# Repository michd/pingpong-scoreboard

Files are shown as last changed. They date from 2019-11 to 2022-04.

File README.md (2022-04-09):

# Pingpong Scoreboard

This is an electronics hardware and firmware project for a Pingpong scoreboard.

Its user interface consists for a 4-digit 7 segment display, a few LEDs, a button for each side of the table, and a button for the scoreboard.

The scoreboard keeps track of the score within the game, within the set (games won each side since power-up) and of the overall score (games won each side, all time).

## Hardware

Since the program for this is really simple, and there isn't much I/O, an ATTiny84 was chose as the microcontroller, of the Microchip/AVR range. It is programmed via ISP, and I'm programming it using a Waveshare AVRISP MKII.

The display is driven using a Maxim Integrated MAX7219. The few extra indication LEDs are also driven by that, since the chip supports up to 8 digits, and the project only requires 4.

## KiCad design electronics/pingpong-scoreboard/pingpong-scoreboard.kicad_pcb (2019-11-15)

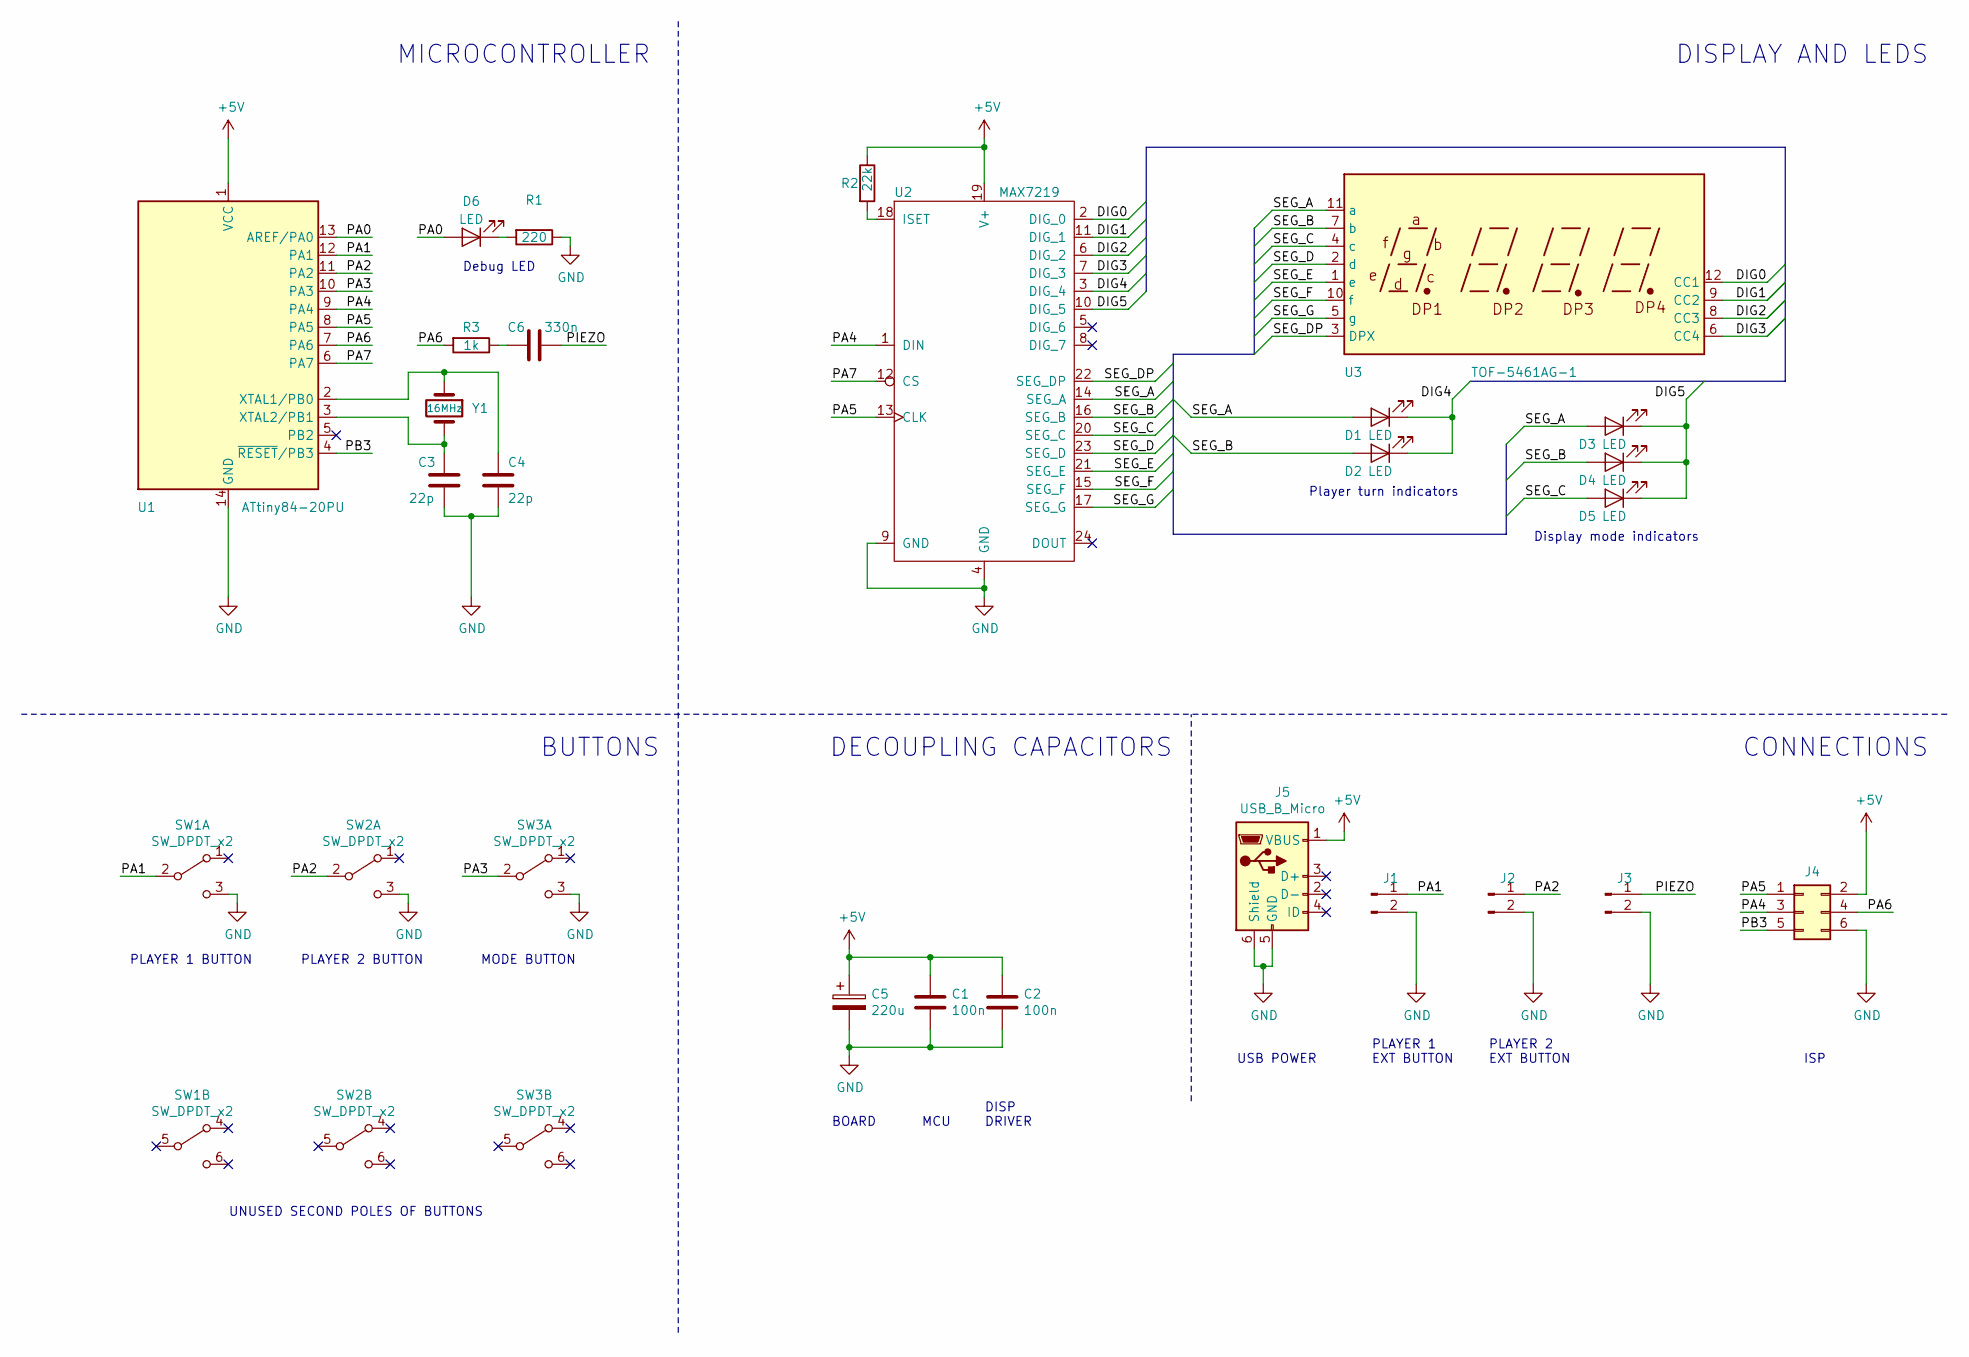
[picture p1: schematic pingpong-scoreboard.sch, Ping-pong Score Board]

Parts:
C1, C2: 100n; C_Disc_D4.3mm_W1.9mm_P5.00mm
C3, C4: 22p; C_Disc_D4.3mm_W1.9mm_P5.00mm
C5: 220u; CP_Radial_D6.3mm_P2.50mm
C6: 330n; C_0603_1608Metric
D1, D2: LED; LED_D5.0mm_Clear
D3, D4, D5: LED; LED_D5.0mm
D6: LED; LED_0603_1608Metric
J1, J2, J3: Conn_01x02_Male; PinHeader_1x02_P2.54mm_Horizontal
J4: Conn_02x03_Odd_Even; IDC-Header_2x03_P2.54mm_Horizontal
J5: USB_B_Micro; USB_Micro-B_Amphenol_10103594-0001LF_Horizontal
R1: 220; R_0603_1608Metric
R2: 22k; R_0603_1608Metric
R3: 1k; R_0603_1608Metric
SW1, SW2, SW3: SW_DPDT_x2; 6-pin-momentary-push-button
U1: ATtiny84-20PU; DIP-14_W7.62mm_LongPads
U2: MAX7219; DIP-24_W7.62mm_LongPads
U3: TOF-5461AG-1; CA56-12CGKWA
Y1: 16MHz; Resonator-2Pin_W10.0mm_H5.0mm

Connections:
+5V: C1.1, C2.1, C5.1, J4.2, J5.1 (VBUS), R2.1, U1.1 (VCC), U2.19 (V+)
/DIG0: U2.2 (DIG_0), U3.12 (CC1)
/DIG1: U2.11 (DIG_1), U3.9 (CC2)
/DIG2: U2.6 (DIG_2), U3.8 (CC3)
/DIG3: U2.7 (DIG_3), U3.6 (CC4)
/DIG4: D1.1 (K), D2.1 (K), U2.3 (DIG_4)
/DIG5: D3.1 (K), D4.1 (K), D5.1 (K), U2.10 (DIG_5)
/PA0: D6.2 (A), U1.13 (AREF/PA0)
/PA1: J1.1, SW1.2 (B), U1.12 (PA1)
/PA2: J2.1, SW2.2 (B), U1.11 (PA2)
/PA3: SW3.2 (B), U1.10 (PA3)
/PA4: J4.3, U1.9 (PA4), U2.1 (DIN)
/PA5: J4.1, U1.8 (PA5), U2.13 (CLK)
/PA6: J4.4, R3.2, U1.7 (PA6)
/PA7: U1.6 (PA7), U2.12 (CS)
/PB3: J4.5, U1.4 (~RESET~/PB3)
/PIEZO: C6.1, J3.1
/SEG_A: D1.2 (A), D3.2 (A), U2.14 (SEG_A), U3.11 (a)
/SEG_B: D2.2 (A), D4.2 (A), U2.16 (SEG_B), U3.7 (b)
/SEG_C: D5.2 (A), U2.20 (SEG_C), U3.4 (c)
/SEG_D: U2.23 (SEG_D), U3.2 (d)
/SEG_DP: U2.22 (SEG_DP), U3.3 (DPX)
/SEG_E: U2.21 (SEG_E), U3.1 (e)
/SEG_F: U2.15 (SEG_F), U3.10 (f)
/SEG_G: U2.17 (SEG_G), U3.5 (g)
GND: C1.2, C2.2, C3.2, C4.2, C5.2, J1.2, J2.2, J3.2, J4.6, J5.5 (GND), J5.6 (Shield), R1.1, SW1.3 (C), SW2.3 (C), SW3.3 (C), U1.14 (GND), U2.4 (GND), U2.9 (GND)
unnamed: C3.1, U1.3 (XTAL2/PB1), Y1.2
unnamed: C4.1, U1.2 (XTAL1/PB0), Y1.1
unnamed: C6.2, R3.1
unnamed: D6.1 (K), R1.2
unnamed: R2.2, U2.18 (ISET)

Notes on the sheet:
Player turn indicators
Display mode indicators
PLAYER 1 BUTTON
PLAYER 2 BUTTON
MODE BUTTON
UNUSED SECOND POLES OF BUTTONS
Debug LED
PLAYER 1 EXT BUTTON
PLAYER 2 EXT BUTTON
ISP
USB POWER
CONNECTIONS
BOARD
MCU
DISP DRIVER
DECOUPLING CAPACITORS
BUTTONS
MICROCONTROLLER
DISPLAY AND LEDS

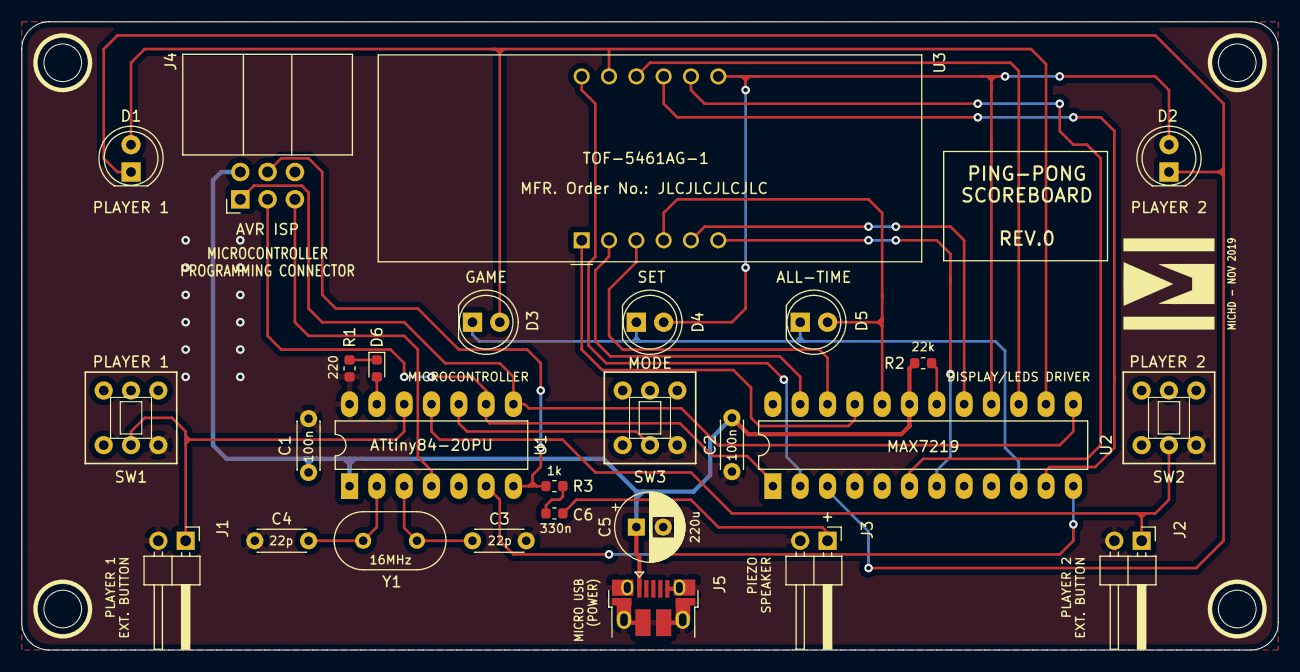
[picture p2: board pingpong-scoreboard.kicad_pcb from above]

Board: 2 copper layers, 116.8 x 58.4 mm, 27 parts (0 on the bottom side), 31 nets.

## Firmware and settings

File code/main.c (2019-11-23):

#include <avr/io.h>
#include <avr/interrupt.h>
#include <avr/eeprom.h>
#include <util/delay.h>
#include "MAX72S19.h"
#include "button.h"
#include "pingpong.h"
#include "animation.h"
#include "tonegen.h"
#include "stdbool.h"
#include "stdint.h"

#define PIN_BTN_PLAYER1 PINA1
#define PIN_BTN_PLAYER2 PINA2
#define PIN_BTN_MODE    PINA3
#define PIN_DISP_DATA   PINA4
#define PIN_DISP_CLK    PINA5
#define PIN_DISP_CS     PINA7
// Pin A6 used for timer 1 output compare match A output

#define TICK_MS 2
#define BTN_PRESS_TICKS 2
#define BTN_LONG_PRESS_TICKS 750

#define PINA_CHANGED(p) ((PINA & (1 << (p))) != (_portACache & (1 << (p))))
#define READ_PINA(p) (PINA & (1 << (p)))
#define BTN_FOR_PIN(p) ((p==PINA1) \
                          ? &_buttons[0] \
                          : (p==PINA2) \
                            ? &_buttons[1] \
                            : &_buttons[2])

#define EEPROM_ADDR_SCORE_P1 (0x00)
#define EEPROM_ADDR_SCORE_P2 (0x02)

#define DEBUG_LED_ON (PORTA |= 0x01);
#define DEBUG_LED_OFF (PORTA &= ~(0x01));
#define DEBUG_TOGGLE_LED (PORTA = (PORTA & 0xFE) | ~(PORTA & 0x01))

static void _ioSetup();
static void _timerSetup();
static void _onPinChangeA(Button *);
static void _checkButtons();
static void _tick();

static volatile Button _buttons[3];
static uint32_t _ticks;
static uint8_t _portACache;

static volatile bool _flagTick;

int main (void) {
  _ioSetup();
  _timerSetup();
  animationInit();
  tonegenInit();

  // References to buttons for player 1, 2, and mode button
  pingpongInit(
      &_buttons[0], &_buttons[1], &_buttons[2],
      EEPROM_ADDR_SCORE_P1,
      EEPROM_ADDR_SCORE_P2);

  // Globally enable interrupts. pretty important.
  sei();

  // Everything done via interrupts from this point
  while (1) {
    _portACache = PINA;

    if (_flagTick) {
      _flagTick = false;
      _tick();
    }
  }
}

static void _ioSetup() {
  // Port A configuration
  // 1 = output in DDRx
  // A:7654 3210
  //   1111 0001: 0xF1 - Pin A7(out) is used for display serial communication
  //                     Pin A6(out) is used for timer1 output compare match A
  //                     Pins A5, A4(out) are used for display serial comm.
  //                     Pins A3-A1(in) are for buttons (w/ interrupt).
  //                     Pin A0(out) is a debug LED.
  DDRA = 0xF1;

  // If a pin is an input and the PORTx bit is 1, pullup is enabled
  // If it is an output the PORTx sets that output level, 1 or 0
  // A:7654 3210
  //   0000 1110 :0x0E - Pins A3-A1 are inputs with pullups, for buttons
  PORTA |= 0x0E | (1 << PIN_DISP_CS); // Also setting chip select high

  // A1: PCINT1
  // A2: PCINT2
  // A3: PCINT3
  // All these are on Pin change interrupt 0

  // Enable interrupt request for interrupt 0
  // Datasheet 9.3.2
  GIMSK |= (1 << (PCIE0));

  // Enable pin changes for pins we're interested in, for interrupt 0
  // Datasheet 9.3.5
  PCMSK0 |= (1 << PCINT1) | (1 << PCINT2) | (1 << PCINT3);

  _portACache = PINA;

  _buttons[0].pin = PIN_BTN_PLAYER1;
  _buttons[1].pin = PIN_BTN_PLAYER2;
  _buttons[2].pin = PIN_BTN_MODE;
  _buttons[0].released = true;
  _buttons[1].released = true;
  _buttons[2].released = true;

  displaySetup(PIN_DISP_CS, PIN_DISP_DATA, PIN_DISP_CLK, 0x00, 0xF, 6);
}

static void _timerSetup() {
  //----------------------------------------------------------------------------
  // Timer / Counter 0 - used for a timing tick every 2ms, produces interrupt
  //----------------------------------------------------------------------------

  // Timer / Counter 0 Control Register A
  TCCR0A = 0x02;
  // 0000 0010 : 0x02
  // |||| ||\\- WGM00, WGM01, Set for CTC (clear timer on compare)
  // |||| \\- Unused
  // ||\\- COM0B1, COM0B0: Compare match output B, disconnectoed
  // \\- COM0A1, COM0A0: Compare match output A, disconnected

  // Timer / Counter 0 Control Register B
  TCCR0B = 0x04;
  // 0000 0100 : 0x04
  // |||| |\\\- CS02, CS01, CS00: Clock select: Main clock / 256
  // |||| \- WGM02
  // ||\\- Reserved, unused
  // \\- FOC0A, FOC0B: Force output compare A/B: irrelevant

  // In TCCR0B, Timer 0's prescaler is set to use a prescaler of 256.
  // This means that the counter counts at a frequency of F_CPU / 256.
  // We're using 16 MHz, so the counter frequency will be 62.5 kHz

  // Timer / Counter 0 Output Compare Register A
  OCR0A = 124;

  // The output compare register contains the value of the counter at which
  // we'll do something. In this case, we'll generate an interrupt.
  // At 62.5 kHz, this means the interrupt will be generated 500 times per
  // second, or once every 2 milliseconds.

  // Timer / Counter 0 Interrupt Mask register
  TIMSK0 = 0x02;
  // 0000 0010 : 0x02
  // |||| |||\- TOIE0: Timer/Counter 0 overflow interrupt enable: off
  // |||| ||\- OC1E0A: Timer/Counter 0 output compare match A enable: on
  // |||| |\- OC1E0B: Timer/Counter 0 output compare match B enable: off
  // \\\\ \- Reserved, unused.

  // In TIMSK0, we're enabling the interrupt for Output compare A. in OCR0A
  // we set the value to compare to, here we're making sure an interrupt will
  // be triggered when Timer/Counter 0's counter value matches what's in there.

  //----------------------------------------------------------------------------
  // Timer / Counter 1 - used for sound output, producing square waves
  //----------------------------------------------------------------------------

  // Timer / Counter 1 Control Register A
  TCCR1A = 0x00;
  // 0000 0000 : 0x00
  // |||| ||\\- WGM11:10: Part of WGM13:10, set to mode 4: CTC with TOP=OCR1A
  // |||| ||              Timer counter will be cleared when it matches output
  // |||| ||              compare register A. This being on makes it so that
  // |||| ||              output compare register combined with the prescaler
  // |||| ||              determine the resulting square wave frequency.
  // |||| \\- Unused
  // ||\\- COM1B1:0: Normal operation, OC1B disconnected: no pin toggling for
  // ||              output compare register B
  // \\- COM1A1:0: Toggle OC1A on Compare Match: Disconnected
  //               Turn this on with notegenToggle(true), will set this to 01.
  //               The OC1A (PA6) pin will then be toggled every time the output
  //               compare register A matches the counter value.

  // Timer / Counter 1 Control Register B
  TCCR1B = 0x0A;
  // 0000 1010 : 0x0A
  // |||| |\\\- CS12:10: Clock select: Main clock / 8
  // |||\ \- WGM13:12: Part of WGM13:10, set to mode 4. See comment for TCCR1A
  // |||               WGM11:10 bits.
  // ||\- Unused
  // |\- ICES1: Input Capture Edge Select: off, irrelevant
  // \- ICNC1: Input Capture Noise Canceler: off, irrelevant

  // Timer / Counter 1 Control Register C
  TCCR1C = 0x00;
  // 0000 0000 : 0x00
  // ||\\ \\\\- Unused
  // \\- FOC1A, FOC1B: Force Output Compate for Channel A, B: irrelevant, only
  //                   relevant in PWM modes, which we aren't using.

  // Output Compare Register 1 A
  OCR1A = 2273; // Set for a frequency of ~440.Hz at the output pin, for testing
  // Later on this should be set up to be quiet initially, and be dynamically
  // changed for playing tunes.
}

static void _onPinChangeA(Button * btn) {
  bool up = READ_PINA(btn->pin);

  if (up) {
    btn->lastUp = _ticks;
  } else {
    btn->lastDown = _ticks;
  }

  btn->down = !up;
}

static void _checkButtons() {
  Button * btn;
  uint8_t i;
  bool wasHeld;

  for (i = 0; i < sizeof(_buttons) / sizeof(Button); i++) {
    btn = &_buttons[i];
    btn->down = !READ_PINA(btn->pin);

    if (btn->down) {
      btn->released = false;
      if (btn->held) continue;

      if ((_ticks - btn->lastDown) > BTN_LONG_PRESS_TICKS) {
        btn->held = true;
        pingpongButtonLongPress(btn);
      }
    } else {
      wasHeld = btn->held;
      if (btn->released) continue;

      if ((_ticks - btn->lastUp) > BTN_PRESS_TICKS) {
        btn->held = false;
        btn->released = true;
        if (!wasHeld) pingpongButtonPress(btn);
      }
    }
  }
}

static void _tick() {
  _ticks++;
  animationTick(_ticks);
  _checkButtons();
  pingpongGameTick();
}

// Interrupt vector 0 triggered
// This vector is used for pin change interrupts on port A
ISR(PCINT0_vect) {
  for (uint8_t i = 0; i < sizeof(_buttons) / sizeof(Button); i++) {
    if (PINA_CHANGED(_buttons[i].pin)) _onPinChangeA(&_buttons[i]);
  }
}

// Interrupt vector for Timer 0 output compare match A triggered
// Used for a 2ms tick for timing things that could do with timing
ISR(TIM0_COMPA_vect) {
  _flagTick = true;
}

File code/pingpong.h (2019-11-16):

#include "stdint.h"
#include "button.h"

#ifndef PINGPONG_H_
 
#define PINGPONG_H_
// TODO: enums are a thing
#define PINGPONG_PLAYER_NONE 0
#define PINGPONG_PLAYER_1    1
#define PINGPONG_PLAYER_2    2

#define PINGPONG_DISPMODE_NONE 0
#define PINGPONG_DISPMODE_GAME 1
#define PINGPONG_DISPMODE_SET  2
#define PINGPONG_DISPMODE_ALL  3

void pingpongInit(Button *, Button *, Button *, uint16_t, uint16_t);
void pingpongGameTick();
void pingpongButtonPress(Button *);
void pingpongButtonLongPress(Button *);
void pingpongSetMode(uint8_t);
void pingpongIndicatePlayerTurn(uint8_t);

#endif /* PINGPONG_H_ */

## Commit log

2019-11-09 Initial commit: start of firmware (buttons, disp)
    Also starts implementing the actual score-keeping logic, but a lot left
    to do.
2019-11-10 Debounce buttons, implement more game logic
2019-11-10 Add LEDs to indicate what's on the display
2019-11-11 Fix MAX72S19 SetLed method, to use correct digit reg
    [MAX72S19.c]
2019-11-11 Indicate with display dot when alltime score saved
    Just a minor visual indicator to let you know it's okay to power off,
    and be sure the score is saved.
2019-11-11 Add animation system
    Using the main tick interrupts, allows running animation implemented
    with a little bit of data, and frame/finished functions. Supports
    infinite animations too.
    Animations can be used for anything, not just display-related things.
2019-11-15 Set up Timer1 for audio out (simple square waves)
    This will be driving a piezo speaker, used for playing a little tune
    when a game ends, and possibly other sound effects.
2019-11-15 Add KiCad schematic
    [pingpong-scoreboard.kicad_pcb, pingpong-scoreboard.sch]
2019-11-15 Lay out PCB components + add piezo output
    [pingpong-scoreboard.kicad_pcb, pingpong-scoreboard.sch]
2019-11-15 Route PCB, set up nice silkscreen
    [pingpong-scoreboard.kicad_pcb, pingpong-scoreboard.sch]
2019-11-16 Move startup, win animation to animation.c
    Also allow clearing animation that is ongoing, which makes it
    immediately execute its final frame.
    Position incrementing in animation is now done by the animation system
    instead of the animation's frame function. Frame functions may still
    manipulate the position, but it's not recommended.
2019-11-16 Put MAX72S19 lib on diet, cut out some cruft
2019-11-23 Add code fix for incorrect display wiring on board
    Oops. The digits were essentially inverted, so now re-assigning them in
    the display driver file instead of bodging the hardware.
    [MAX72S19.c]
2019-11-23 Rewrite button press/long press handling
    This was very buggy, with double presses and wrong buttons being
    triggered. Now seems to work quite reliably without any double or missed
    presses, let alone the display mode occasionally being changed when
    pressing a player button. Still not sure what caused that last one, but
    I'm guessing it's race conditions.
    [main.c]
